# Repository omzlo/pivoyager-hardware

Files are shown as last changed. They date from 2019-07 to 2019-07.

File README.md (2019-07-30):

# Pivoyager Hardware
Hardware design files for the PiVoyager

See https://www.omzlo.com/articles/pivoyager-the-smart-ups-for-the-raspberry-pi

## License

All hardware is licensed under [Creative Commons Attribution-ShareAlike 4.0 International (CC BY-SA 4.0)](https://creativecommons.org/licenses/by-sa/4.0/)

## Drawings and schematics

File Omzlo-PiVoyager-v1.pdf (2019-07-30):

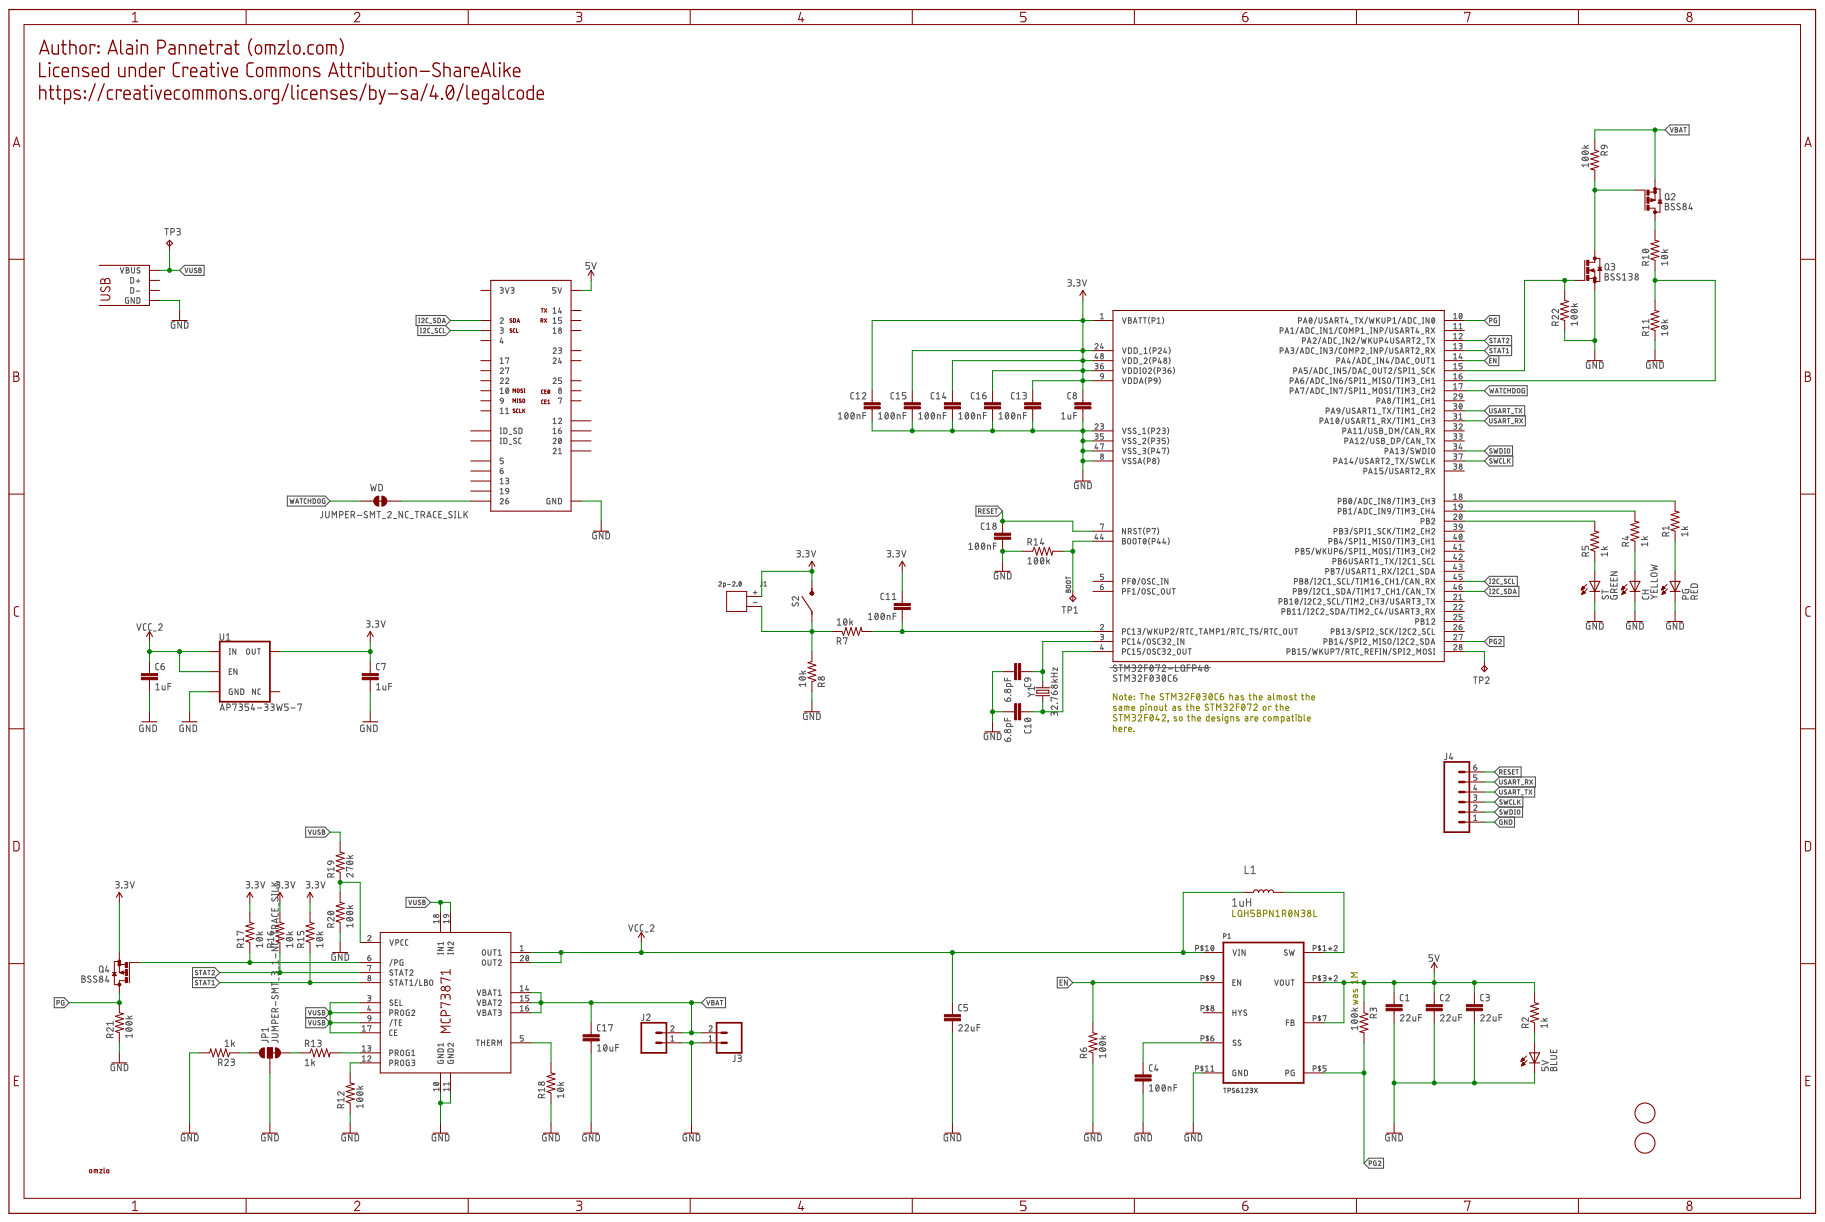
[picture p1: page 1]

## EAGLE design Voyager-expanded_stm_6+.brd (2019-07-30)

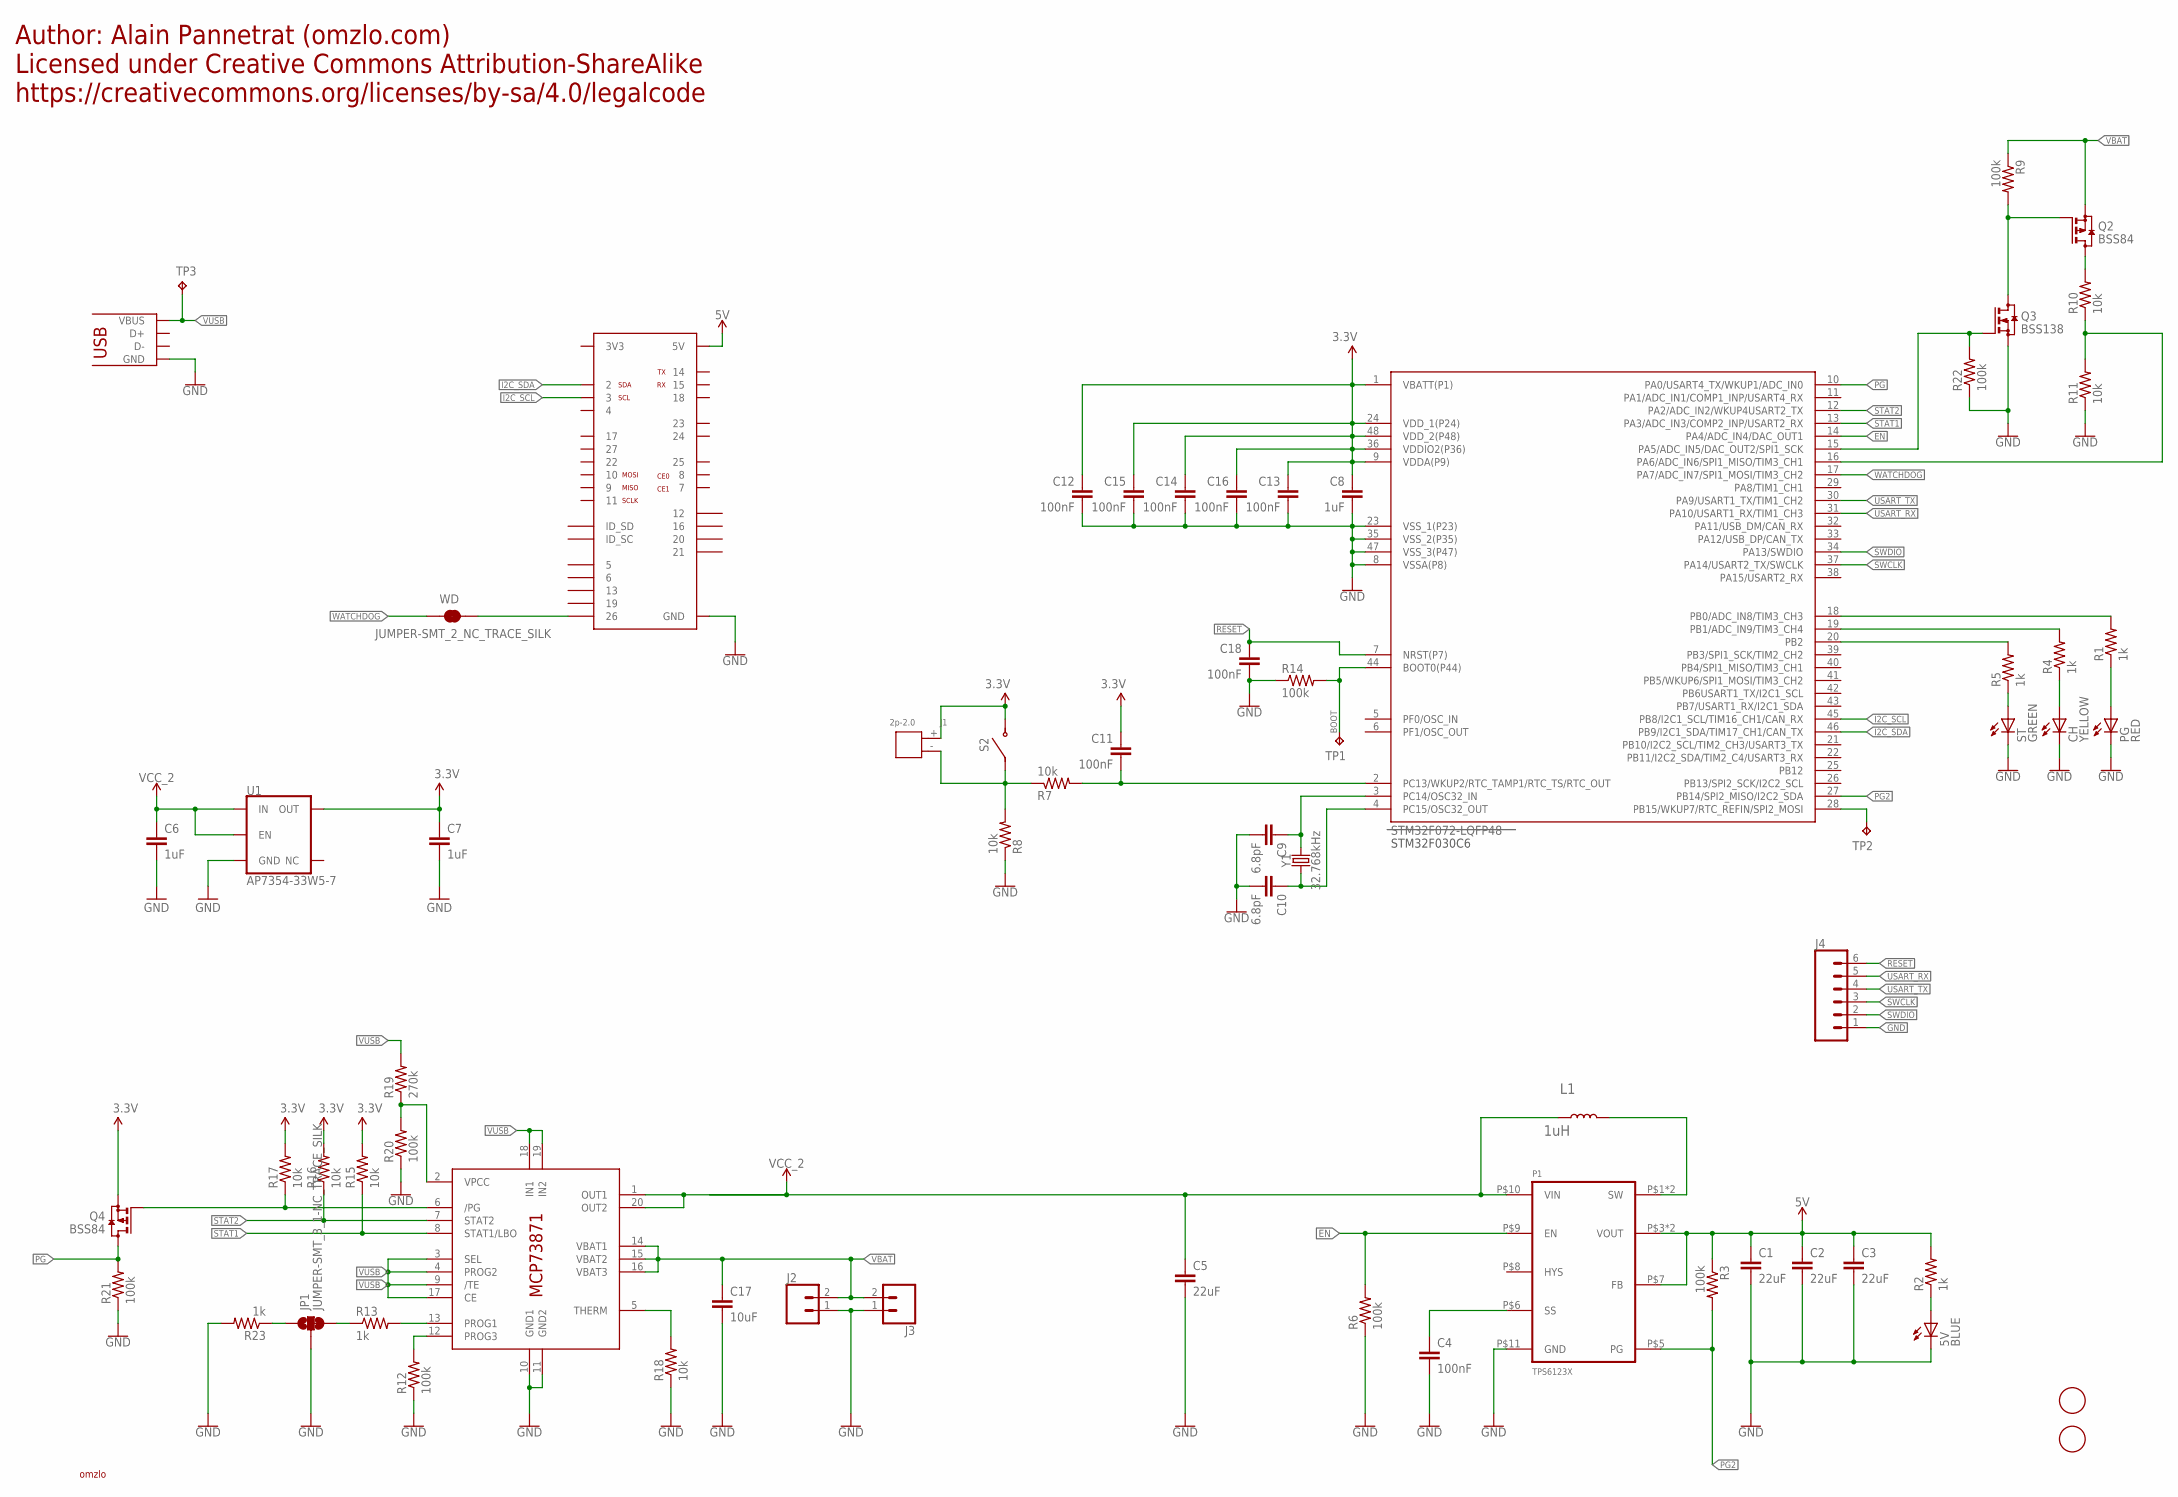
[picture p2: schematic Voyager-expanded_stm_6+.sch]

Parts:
5V: BLUE; CHIP-LED0805
C1, C2, C3, C5: 22uF; C1206
C4, C11, C12, C13, C14, C15, C16, C18: 100nF; C0603
C6, C7, C8: 1uF; 0805
C9, C10: 6.8pF; C0603
C17: 10uF; C0805
CH: YELLOW; CHIP-LED0805
IC1: MCP73871; QFN20
J1: 2p-2.0; H2-2.0-6X4.5MM
J2: CONN_021X02_NO_SILK; 1X02_NO_SILK
J3: CONN_02-JST-2MM-SMT; JST-2-SMD
J4: CONN_06NO_SILK_FEMALE_PTH; 1X06_NO_SILK
JP1: JUMPER-SMT_3_1-NC_TRACE_SILK; SMT-JUMPER_3_1-NC_TRACE_SILK
L1: 1uH; L5040S
P1: TPS6123X; PVSON-10
PG: RED; CHIP-LED0805
Q2, Q4: BSS84; SOT23
Q3: BSS138; SOT23
R1, R2, R4, R5, R13, R23: 1k; R0603
R3, R6, R9, R12, R14, R20, R21, R22: 100k; R0603
R7, R8, R10, R11, R15, R16, R17, R18: 10k; R0603
R19: 270k; R0603
S2: TACT-SWITCH; ALPS-SKSCPDE010
ST: GREEN; CHIP-LED0805
TP1, TP2, TP3: TPB1,27; B1,27
U1: AP7354-33W5-7; SOT23-5
U$1: RASPBERRY-PI-GPIO; 2X20
U$2: STM32F072-LQFP48; LQFP48
U$3: USB-MICROB
U$4, U$9: FIDUCIAL; FIDUCIAL_1MM
U$6: OMZLO
WD: JUMPER-SMT_2_NC_TRACE_SILK; SMT-JUMPER_2_NC_TRACE_SILK
Y1: 32.768kHz; CRYSTAL-SMD-3.2X1.5MM

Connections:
3.3V: C7.1, C8.1, C11.1, C12.1, C13.1, C14.1, C15.1, C16.1, J1.+, Q4.2 (S), R15.2, R16.2, R17.2, S2.P$3, S2.P$4, U1.5 (OUT), U$2.1 (VBATT(P1)), U$2.9 (VDDA(P9)), U$2.24 (VDD_1(P24)), U$2.36 (VDDIO2(P36)), U$2.48 (VDD_2(P48))
3V3: U$1.1 (3V3), U$1.17 (3V3)
5V: C1.1, C2.1, C3.1, P1.P$3 (VOUT), P1.P$4 (VOUT), P1.P$7 (FB), R2.2, R3.1, U$1.2 (5V), U$1.4 (5V)
BOOT: R14.2, TP1.TP, U$2.44 (BOOT0(P44))
EN: P1.P$9 (EN), R6.2, U$2.14 (PA4/ADC_IN4/DAC_OUT1)
GND: 5V.C, C1.2, C2.2, C3.2, C4.2, C5.2, C6.2, C7.2, C8.2, C9.2, C10.2, C12.2, C13.2, C14.2, C15.2, C16.2, C17.2, C18.2, CH.C, IC1.10 (GND1), IC1.11 (GND2), J2.1, J3.1 (2), J4.1, JP1.2, P1.P$11 (GND), PG.C, Q3.2 (S), R6.1, R8.1, R11.1, R12.1, R14.1, R18.1, R20.1, R21.1, R22.1, R23.2, ST.C, U1.2 (GND), U$1.6 (GND), U$1.9 (GND), U$1.14 (GND), U$1.20 (GND), U$1.25 (GND), U$1.30 (GND), U$1.34 (GND), U$1.39 (GND), U$2.8 (VSSA(P8)), U$2.23 (VSS_1(P23)), U$2.35 (VSS_2(P35)), U$2.47 (VSS_3(P47)), U$3.GND, U$3.MT1 (GND), U$3.MT2 (GND), U$3.P$1 (GND), U$3.P$2 (GND), U$3.P$3 (GND), U$3.P$4 (GND)
I2C_SCL: U$1.5 (3), U$2.45 (PB8/I2C1_SCL/TIM16_CH1/CAN_RX)
I2C_SDA: U$1.3 (2), U$2.46 (PB9/I2C1_SDA/TIM17_CH1/CAN_TX)
unnamed: C9.1, U$2.3 (PC14/OSC32_IN), Y1.P$2 (2)
unnamed: C10.1, U$2.4 (PC15/OSC32_OUT), Y1.P$1 (1)
unnamed: IC1.2 (VPCC), R19.1, R20.2
unnamed: R10.1, R11.2, U$2.16 (PA6/ADC_IN6/SPI1_MISO/TIM3_CH1)
unnamed: IC1.5 (THERM), R18.2
unnamed: IC1.12 (PROG3), R12.2
unnamed: IC1.13 (PROG1), R13.2
unnamed: R4.2, U$2.19 (PB1/ADC_IN9/TIM3_CH4)
unnamed: CH.A, R4.1
unnamed: R5.2, U$2.20 (PB2)
unnamed: Q2.3 (D), R10.2
unnamed: C4.1, P1.P$6 (SS)
unnamed: Q2.1 (G), Q3.3 (D), R9.2
unnamed: L1.2, P1.P$1 (SW), P1.P$2 (SW)
unnamed: R5.1, ST.A
unnamed: R1.2, U$2.18 (PB0/ADC_IN8/TIM3_CH3)
unnamed: 5V.A, R2.1
unnamed: TP2.TP, U$2.28 (PB15/WKUP7/RTC_REFIN/SPI2_MOSI)
unnamed: J1.-, R7.1, R8.2, S2.P$1, S2.P$2
unnamed: PG.A, R1.1
unnamed: U$1.37 (26), WD.2
unnamed: JP1.3, R13.1
unnamed: JP1.1, R23.1
PG: Q4.3 (D), R21.2, U$2.10 (PA0/USART4_TX/WKUP1/ADC_IN0)
PG2: P1.P$5 (PG), R3.2, U$2.27 (PB14/SPI2_MISO/I2C2_SDA)
PG_MCP: IC1.6 (/PG), Q4.1 (G), R17.1
RESET: C18.1, J4.6, U$2.7 (NRST(P7))
STAT1: IC1.8 (STAT1/LBO), R15.1, U$2.13 (PA3/ADC_IN3/COMP2_INP/USART2_RX)
STAT2: IC1.7 (STAT2), R16.1, U$2.12 (PA2/ADC_IN2/WKUP4USART2_TX)
SWCLK: J4.3, U$2.37 (PA14/USART2_TX/SWCLK)
SWDIO: J4.2, U$2.34 (PA13/SWDIO)
SWITCH: C11.2, R7.2, U$2.2 (PC13/WKUP2/RTC_TAMP1/RTC_TS/RTC_OUT)
USART_RX: J4.5, U$2.31 (PA10/USART1_RX/TIM1_CH3)
USART_TX: J4.4, U$2.30 (PA9/USART1_TX/TIM1_CH2)
VBAT: C17.1, IC1.14 (VBAT1), IC1.15 (VBAT2), IC1.16 (VBAT3), J2.2, J3.2 (1), Q2.2 (S), R9.1
VBAT_EN: Q3.1 (G), R22.2, U$2.15 (PA5/ADC_IN5/DAC_OUT2/SPI1_SCK)
VCC_2: C5.1, C6.1, IC1.1 (OUT1), IC1.20 (OUT2), L1.1, P1.P$10 (VIN), U1.1 (IN), U1.3 (EN)
VUSB: IC1.3 (SEL), IC1.4 (PROG2), IC1.9 (/TE), IC1.17 (CE), IC1.18 (IN1), IC1.19 (IN2), R19.2, TP3.TP, U$3.VBUS
WATCHDOG: U$2.17 (PA7/ADC_IN7/SPI1_MOSI/TIM3_CH2), WD.1

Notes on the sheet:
STM32F030C6
Author: Alain Pannetrat (omzlo.com) Licensed under Creative Commons Attribution-ShareAlike https://creativecommons.org/licenses/by-sa/4.0/legalcode

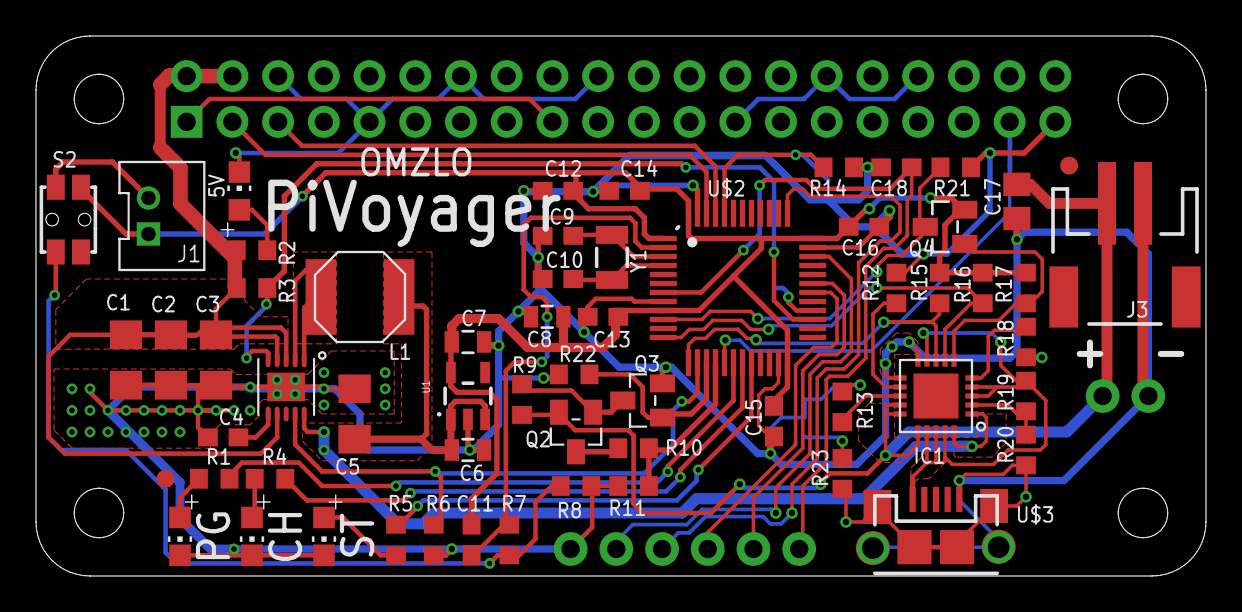
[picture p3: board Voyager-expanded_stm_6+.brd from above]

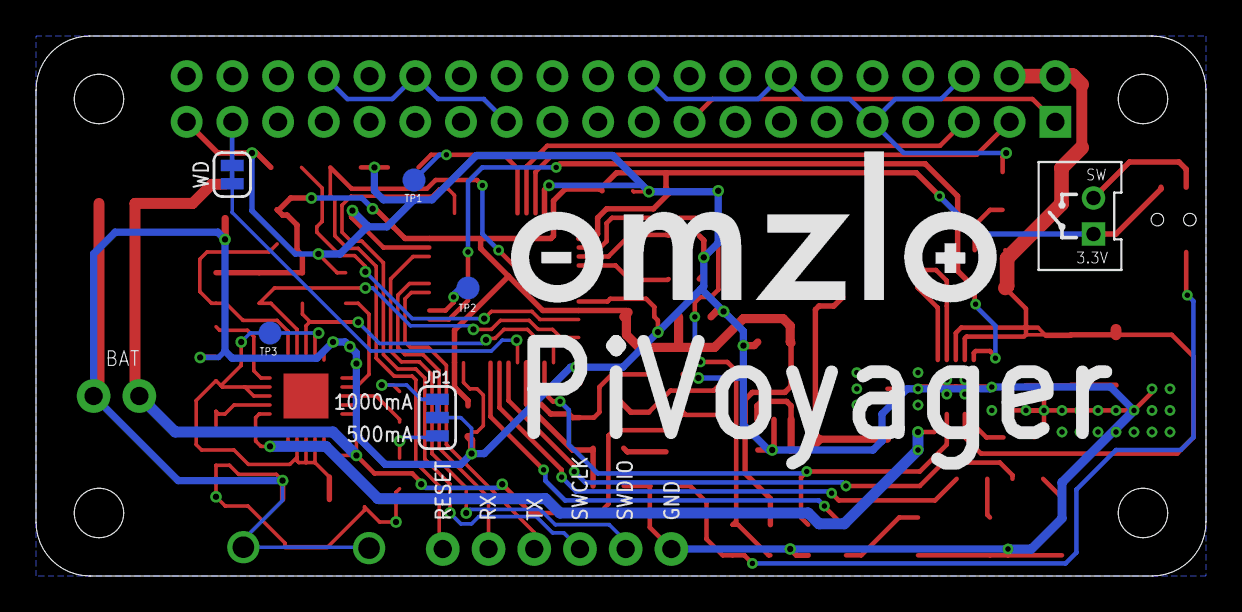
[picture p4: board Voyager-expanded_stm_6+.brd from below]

Board: 2 copper layers, 65.0 x 30.0 mm, 69 parts (6 on the bottom side), 47 nets.

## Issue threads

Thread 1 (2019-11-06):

JP1 pads doesn't match documentation?

m-kozlowski, 2019-11-06:
[Documentation](https://www.omzlo.com/articles/pivoyager-installation-and-tutorial#changing-the-charge-current-to-500ma) says that in order to reduce charging current to 500mA I need to cut existing trace on JP1 and connect two bottom pads, but it looks to me that pads are, top to bottom:
PAD1: R13 -> PROG1
PAD2: GND
PAD3: R23 -> GND
So doing as docs says we'd end up with PROG1 floating and R23 connecting ground to ground.

omzlo, 2019-11-06:
Well, this is embarrassing: you are absolutely correct. This is a bug in our hardware :-(
The only workaround is to replace R13 with a 2K resistor and keep the original solder trace as is (uncut).

There seems to have been some kind of version mismatch or regression in our production. The correct schematic (from a prior prototype) looks like this:

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

meinnamehier, 2019-11-20:
So i already cut the trace and soldered across the other pad.
Do i need to revert that? What if I keep it like this?
I only just hooked up a battery last night and read about the bug today.

m-kozlowski, 2019-11-20:
You're running out of specification. I can't find in datasheet anything about leaving PROG1 floating, so let's just assume you're somewhere far, far right on [this chart](http://kotlet.empeka.pl/rand/mcp73871-figure-2-3.png)
You should revert. Or solder another 1K resistor across the cut trace, so you'll have desired 500mA charge current.

meinnamehier, 2019-11-21:
I reverted last night and everything seems to be working fine.
Based on your assumption, at least the current would have been very low instead of catastrophically high.
I just wish that I had bee informed in a more active way about this fault, considering we are dealing with LiPo batteries, that can be dangerous when handled incorrectly.

omzlo, 2019-11-21:
> I just wish that I had bee informed in a more active way about this fault, considering we are dealing with LiPo batteries, that can be dangerous when handled incorrectly.

We are sorry about this bug, which was only discovered recently thanks to the input provided by @m-kozlowski . This should not have happened of course, and we will correct this in the next version.

As noted above, the simplest way to go down to 500mA charging current is to keep the default trace on JP1 (or bridge it if it has already been cut) and replace R13 with a 2K resistor.

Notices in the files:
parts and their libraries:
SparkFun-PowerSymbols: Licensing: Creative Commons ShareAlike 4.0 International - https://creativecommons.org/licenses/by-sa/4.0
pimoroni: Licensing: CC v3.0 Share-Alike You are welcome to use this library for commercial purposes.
